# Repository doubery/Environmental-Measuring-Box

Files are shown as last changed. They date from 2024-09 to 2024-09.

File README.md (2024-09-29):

# Environmental-Measuring-Box
ESP32-based environmental measuring box for volume, temperature, humidity, air humidity, particulate matter, GPS

All measured data are sent to an influx database and in my case analyzed and displayed using grafana.

# Circuit diagram

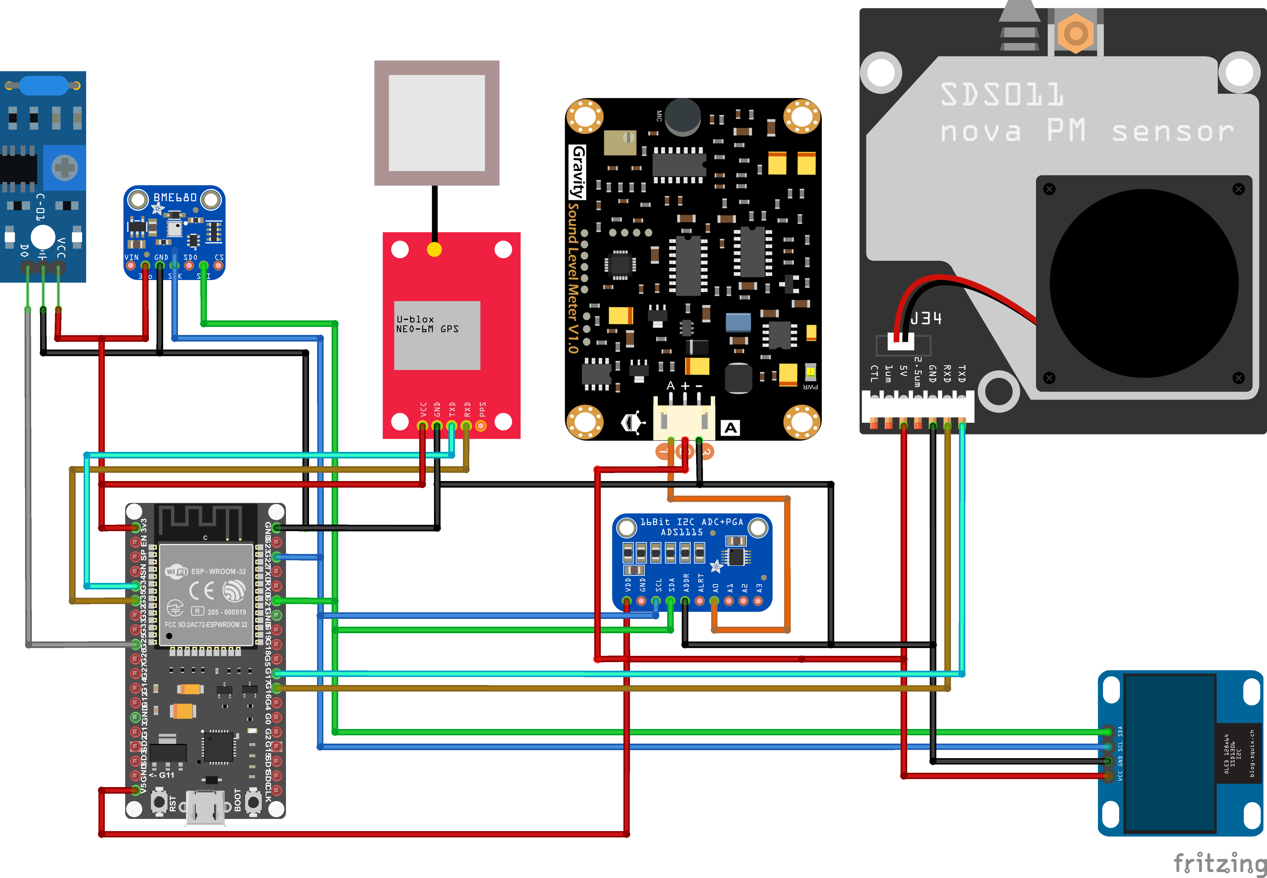
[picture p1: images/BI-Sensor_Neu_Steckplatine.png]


# Installation
Once all the parts have been printed, they can be assembled using m2 hexagon socket screws. <br/>
The ESP should be located on the adapter board and all sensors should be connected as follows (please refer to the wiring diagram). <br/>

#GPS#

TX = RX2 GPIO34       //GPS-RX2 <br/>
RX = TX2 GPIO35       //GPS-TX2 <br/>
GND <br/>
3.3V <br/>

#SDS#

RX = Serial2	  GPIO017   //SDS-RX1 <br/>
TX = Serial2   	GPIO016   //SDS-TX1 <br/>
GND <br/>
5V <br/>

#ADS1115# !I2C!

SDA = GPIO 21 <br/>
SCL = GPIO 22 <br/>
GND <br/>
5V <br/>

BME680 !I2C!

SDA = GPIO 21 <br/>
SCL = GPIO 22 <br/>
GND <br/>
3.3V <br/>

#DF-Robot-Micro#

Analog = ADS1115 A0 <br/>
GND <br/>
5V <br/>

#Shake Sensor#

PIN 25 <br/>
GND  <br/>
3,3V <br/>

Display !I2C!
SDA = GPIO 21 <br/>
SCL = GPIO 22 <br/>
GND <br/>
3,3V <br/>

The first Scetch (Webconfig.ino) can now be compiled and uploaded to the ESP, pay attention to the correct WLAN data on line 29 and 30. <br/>
If the ESP restart is completed, the IP (find out via your router) of the ESP can be called up. <br/>
It may also work to simply put the link in your browser http://Station.local <br/>

Now the basic data for communication with your InfluxDB can be stored:

- Name of the sensor
- Destination address of the InfluxDB
- InfluxDB token
- InfluxDB organization
- InfluxDB Bucket

Once the entered data has been accepted, the main firmware (Station-V1.x) can be uploaded.

After this, the sensor is restarting and is now connected to your WiFi.  <br/>
If you want to disconnect the sensor of your wifi, to connect to another WiFi, go to the webpage over the ip address, or http://station_< your defined number in the webconfig >.local  <br/>
Now the should restart and starts a hotspot. You can now follow the steps on the display. <br/>
(Or simply connect a Mobile device to the hotspot and follow the steps on the phone) <br/>

# Used Parts

- ESP32‑IO Development Expansion Board
- ESP32 NodeMCU (Check the correct PIN-Number)
- GPS GY-NEO6MV2
- DfRobot Sound Level Meter
- Analog-Digital-Converter ADS1115
- Temp/Humidity BME680
- Dust-Sensor SDS011 with little pipe of ~3cm (8mm) <br/>
  INFO: On the original cable, the well-known JST 2.54 connectors were attached to the side of the esp
- Cylinder head screws Hexagon socket DIN 912 2&4mm
- AZDelivery 0.96 Zoll OLED Display
- AZDelivery SW420 Vibration Sensor
- Jumper Cables

# Pictures

Fully assembled sensor <br/>


Webconfig <br/>
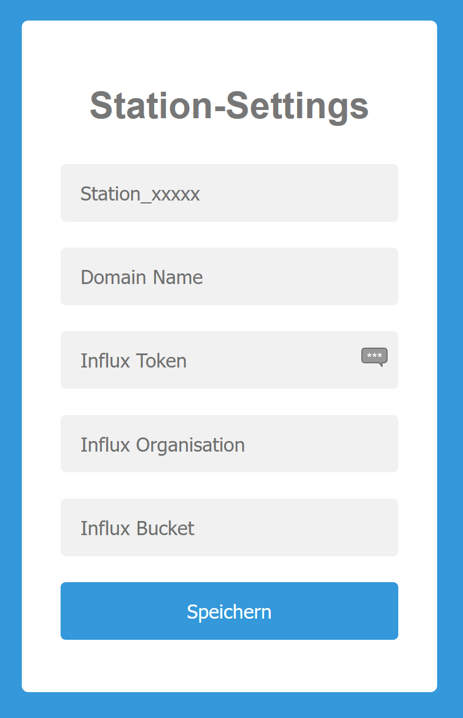
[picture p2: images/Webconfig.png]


Settings page after uploaded firmware "station-V1.7.bin" <br/>
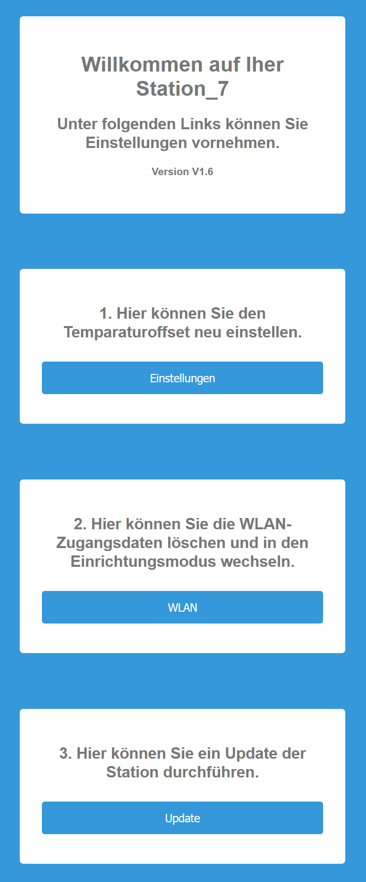
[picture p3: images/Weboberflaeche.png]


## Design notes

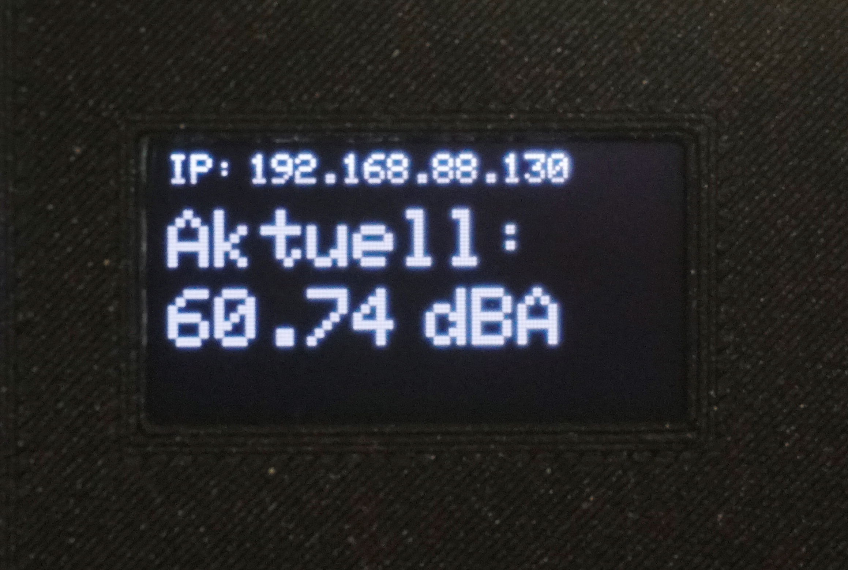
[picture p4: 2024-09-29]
images/Messung_aktuell_Ausschnitt.JPG

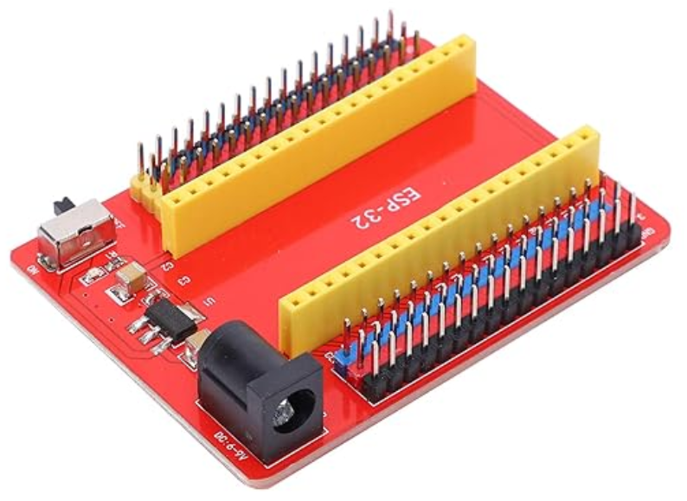
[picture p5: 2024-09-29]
images/Adapterplatine.png

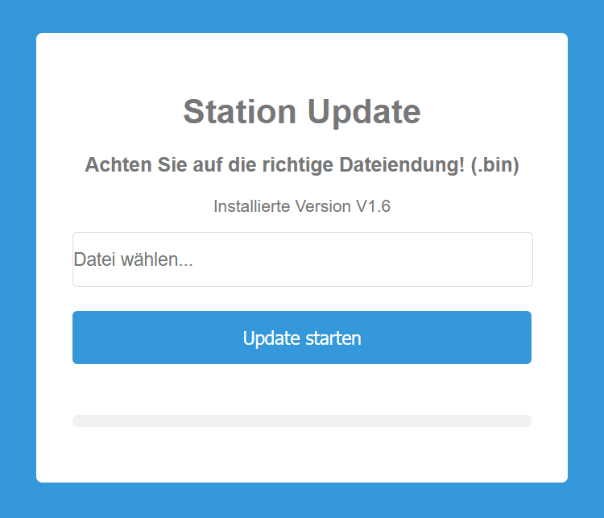
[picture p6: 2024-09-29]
images/Update.png

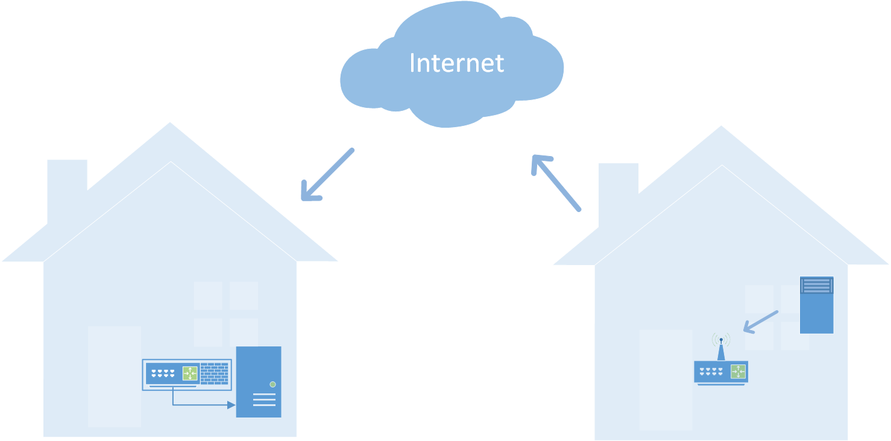
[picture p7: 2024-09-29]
images/Überblick.png

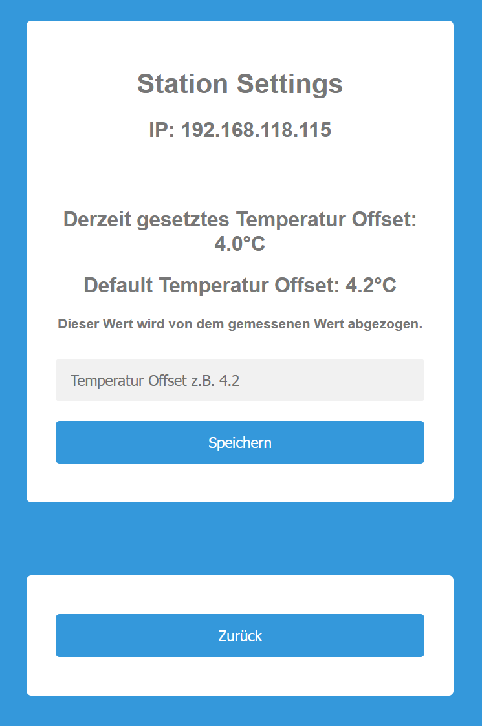
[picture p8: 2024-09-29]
images/Temp-Offset.png

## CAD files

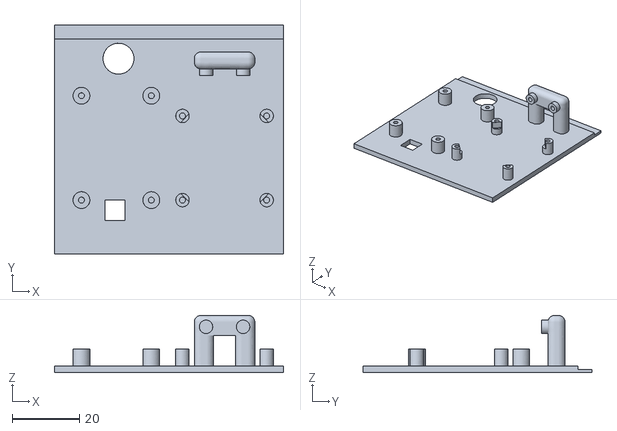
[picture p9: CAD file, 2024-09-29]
3d-print-parts/Zwischenboden-.stl
68.0 x 68.0 x 17.0

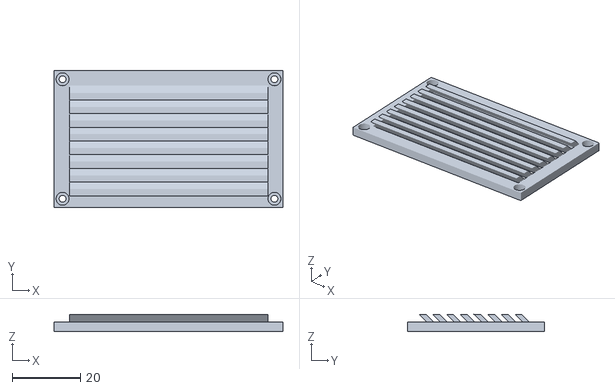
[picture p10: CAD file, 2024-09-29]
3d-print-parts/Lamellen.stl
66.9 x 39.9 x 5.00

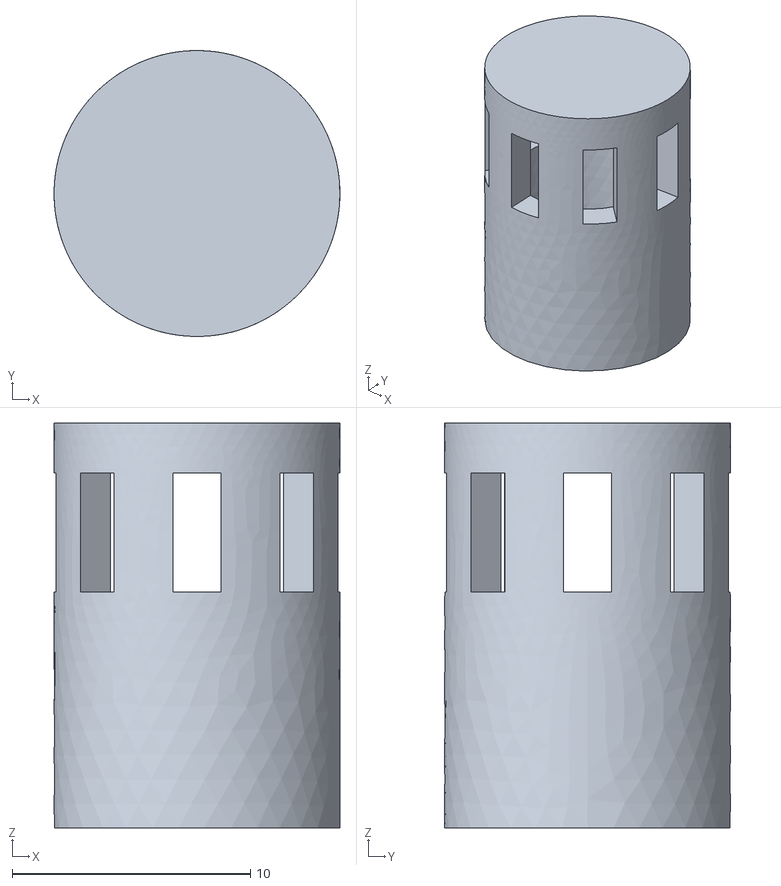
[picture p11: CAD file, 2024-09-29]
3d-print-parts/Staubkappe-SDS011.stl
12.0 x 12.0 x 17.0

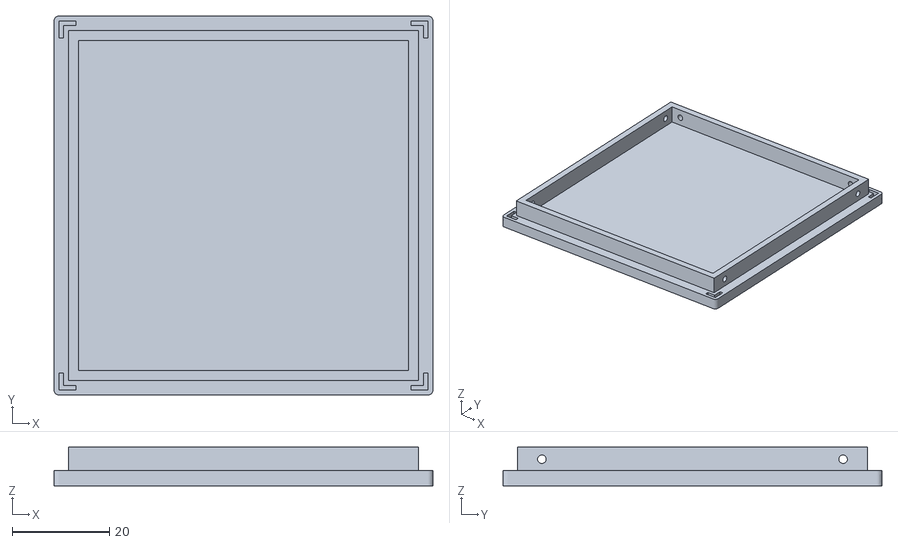
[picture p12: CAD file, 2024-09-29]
3d-print-parts/Deckel.stl
78.0 x 78.0 x 8.00

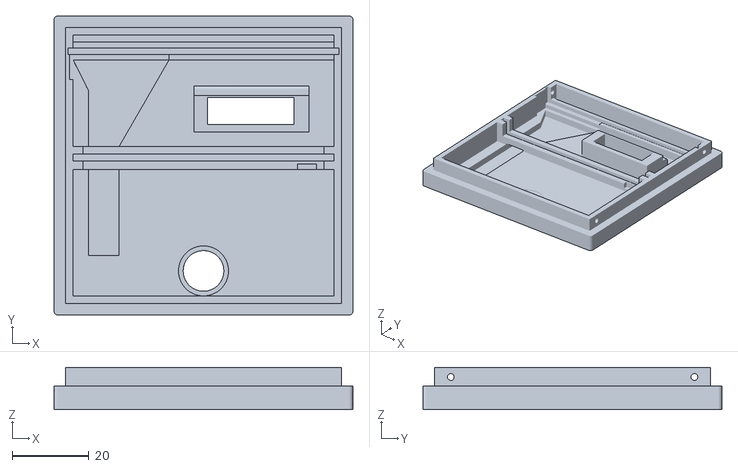
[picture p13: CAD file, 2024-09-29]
3d-print-parts/Boden-ohne-Display.stl
78.0 x 78.0 x 11.0

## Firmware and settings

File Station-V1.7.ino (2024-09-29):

//Umweltdaten und Laermmesssensor der BI-LZH mit OLED
#include <WiFiManager.h>
//#include <WiFiClient.h>
//#include <WiFiClientSecure.h>
#include <InfluxDbClient.h>
#include "Adafruit_BME680.h"
#include "SdsDustSensor.h"
#include <TinyGPS++.h>
#include <HardwareSerial.h>
#include <Wire.h>
#include <SPI.h>
#include <Adafruit_Sensor.h>
#include <Adafruit_ADS1X15.h>
#include <Update.h>
#include <WebServer.h>
#include <ESPmDNS.h>
#include <Preferences.h>
#include <Adafruit_GFX.h>
#include <Adafruit_SSD1306.h>

//OLED-Groesse festlegen
#define SCREEN_WIDTH 128 // OLED display width, in pixels
#define SCREEN_HEIGHT 64 // OLED display height, in pixels
#define OLED_RESET -1 

//Deklaration des SSD1306 display verbunden ueber I2C (SDA, SCL pins)
Adafruit_SSD1306 display(SCREEN_WIDTH, SCREEN_HEIGHT, &Wire, -1);

//==============================================================
//                     Festlegung der globalen Variablen
//==============================================================
String device, sname, snr, sversion, ssid, wpakey, tempoffset, sealevel, dname, idbtoken, idborg, idbbucket, settings, delwifiok, updates, info, ip;
int shakepinstate = 0; 
int display_available = 1;
int period = 30000;
unsigned long time_now = 0;

#define shakepin 25

char myIpString[24];

//Setzen der Zeitzone, falls SSL Verwendet wird ist dies notwendig
// Set timezone string according to https://www.gnu.org/software/libc/manual/html_node/TZ-Variable.html
//  Central Europe: "CET-1CEST,M3.5.0,M10.5.0/3"
#define TZ_INFO "CET-1CEST,M3.5.0,M10.5.0/3"

//==============================================================
//                     SSL-Zertifikat wird nicht benoetigt
//==============================================================
const char* root_ca = "";

//==============================================================
//                     Webserverconfig
//==============================================================
//Festlegung des Style fuer die Weboberflaeche
String style =
"<style>#file-input,input{width:100%;height:44px;border-radius:4px;margin:10px auto;font-size:15px}"
"input{background:#f1f1f1;border:0;padding:0 15px}body{background:#3498db;font-family:sans-serif;font-size:14px;color:#777}"
"#file-input{padding:0;border:1px solid #ddd;line-height:44px;text-align:left;display:block;cursor:pointer}"
"#bar,#prgbar{background-color:#f1f1f1;border-radius:10px}#bar{background-color:#3498db;width:0%;height:10px}"
"form{background:#fff;max-width:380px;margin:75px auto;padding:30px;border-radius:5px;text-align:center}"
".btn{background:#3498db;color:#fff;cursor:pointer}</style>";

//Fetlegung der delwifi Website
String wifi = 
"<meta http-equiv=content-type content=text/html; charset=utf-8>"
"<form action=delwifi>"
"<h1>Station WiFi-Settings</h1>"
"<h2>WLAN Zugangsdaten wirklich löschen?</h2>"
"<h2>Im Anschluss bitte den Anweisungen auf dem Display folgen.</h2>"
"<input type=submit onclick=check(this.form) class=btn value=Löschen></form>"
"<form action=info>"
"<input type=submit onclick=check(this.form) class=btn value=Zurück></form>"
"<script>"
"</script>" + style;

//Festlegung der saved Website
String saved = 
"<meta http-equiv=content-type content=text/html; charset=utf-8>"
"<form action=saved>"
"<h1>Station-Einstellungen wurden erfolgreich gesetzt!</h1>"
"<h2>Die Station startet nun neu, danach sind die Einstellungen übernommen.</h2></form>"
"<script>"
"</script>" + style;

//Webserver auf Port 80 legen
WebServer server(80);

//Flashspeicher initialisieren
Preferences preferences;

//Verschluesselung zur uebertragung der Daten, noch nicht aktiv fehlende SSL Unterstuetzung
//WiFiClientSecure client2;

//Influx client Instanz erstellen
InfluxDBClient client;

//Setzen der Software-Serial-Pins für GPS
#define RX2 32 //GPS-RX2 alt34
#define TX2 33 //GPS-TX2 alt35

//Anlegen der Instanzen fuer die Sensoren
Adafruit_ADS1115 ads;
Adafruit_BME680 bme;
SdsDustSensor sds(Serial2);
TinyGPSPlus gps;
HardwareSerial SerialGPS(1);

//Double Struct fuer die Daten des GPS-Empfaengers (Vorgabe der Library)
struct GpsDataState_t {
  double originLat = 0;
  double originLon = 0;
  double originAlt = 0;
  double distMax = 0;
  double dist = 0;
  double altMax = -999999;
  double altMin = 999999;
  double spdMax = 0;
  double prevDist = 0;
};
GpsDataState_t gpsState = {};

//Einstellen des ADS1115 auf den richtigen Messbereich
int adc;
float maxvolt = 6.144, volt, vdd, dbvalue = 0.0;

//Funktion zum loeschen der WLAN-Zugangsdaten
void delWifi(){
  preferences.remove("ssid");
  preferences.remove("wpakey");
  preferences.end();
  Serial.println("WLAN-Daten erfolgreich geloescht!");
  server.sendHeader("Connection", "close");
  //Rufe die Seite delwifiok auf
  server.send(200, "text/html", delwifiok);
  delay(10000);
  ESP.restart();
}

//Funktion zur speicherung der korrektur Einstellungen
void save(){
  tempoffset = server.arg("tempoffset");
  if (tempoffset != ""){//Temperatur Offset z.B. 4.2
    preferences.putString("tempoffset", tempoffset);
    Serial.println("Temperatur-Offset erfolgreich gespeichert!");
  }else{
    preferences.putString("tempoffset", "4.2");
    Serial.println("Temperatur-Offset erfolgreich gespeichert!");
  }
  preferences.end();
  server.sendHeader("Connection", "close");
  //Rufe die Seite /saved auf
  server.send(200, "text/html", saved);
  delay(10000);
  ESP.restart();
}

//Funktion zum Auslesen des Status des Shakepin Sensors
bool read_shakepin(){
  if (digitalRead(shakepin) == HIGH){
    return true;
  }else{
    return false;
  }
}

//==============================================================
//                           SETUP
//==============================================================
void setup() {
  Serial.begin(9600);
  delay(250);
  
  //Display starten
  if(!display.begin(SSD1306_SWITCHCAPVCC, 0x3C)) { // Address 0x3D for 128x64
    Serial.println("Kein Display erkannt, starte ohne Displaykonfiguration");
    //setze variable display_available auf 0 wenn kein display erkannt
    display_available = 0;
    for(;;);
  }
  //if abfrage wenn display_available == 0, dann ueberspringen, sonst initialisieren
  if(display_available == 1){
    display.clearDisplay();
    display.display();
    display.setTextSize(1);
    display.setTextColor(WHITE);
    display.setCursor(16, 20);
    display.setTextSize(2);
    display.println("-Starte-");
    display.display();
  }
  delay(500);
  
  //Serielle Schnittstelle fuer den GPS-Sensor einrichten
  SerialGPS.begin(9600, SERIAL_8N1, RX2, TX2);
  delay(250);
  
  //ADC starten
  ads.begin();
  delay(250);
  
  //SDS01 Starten
  sds.begin();
  delay(250);
    
  //Ausgabe der SDS01 Fiirmwareversion
  Serial.println("");
  Serial.println(sds.queryFirmwareVersion().toString()); 
  delay(50);
  //Serial.println(sds.setQueryReportingMode().toString());
  //Serial.println(sds.setActiveReportingMode().toString());
  //Serial.println(sds.setContinuousWorkingPeriod().toString());
  delay(50);
  //Temperatursensor starten
  bme.begin();
  delay(50);
  //EEPROM Einlesen
  preferences.begin("S-Settings", false);
  //ADS Gain eistellen
  ads.setGain(GAIN_ONE);
  //Festlegung des Shakepin Pins
  pinMode(shakepin, INPUT);
  
  //Auslesen der Einstellungen aus dem Flashspeicher
  sname = preferences.getString("sname", "");
  snr = preferences.getString("snr", "");
  dname = preferences.getString("dname", "");
  dname = dname + ":8086";
  idbtoken = preferences.getString("idbtoken", "");
  idborg = preferences.getString("idborg", "");
  idbbucket = preferences.getString("idbbucket", "");
  sversion = preferences.getString("sversion", "");
  ssid = preferences.getString("ssid", "");
  wpakey = preferences.getString("wpakey", "");
  tempoffset = preferences.getString("tempoffset", "");
  sealevel = preferences.getString("sealevel", "");
  //Wenn das tempoffset 0.00 oder leer ist, setze es auf 4.2 (Standardwert)
  if(tempoffset == "0.00" || tempoffset == ""){
    tempoffset = "4.2";
  }
  //Wenn das sealevel 0.00 oder leer ist, setze es auf 1013.25 (Standardwert)
  if(sealevel == "0.00" || sealevel == ""){
    sealevel = "1013.25";
  }
  //Ausgabe diverser Infos beim Start
  Serial.println("Daten aus dem Speicher:");
  Serial.println(sname.c_str());
  Serial.println(snr);
  Serial.println(sversion);
  Serial.println(dname.c_str());
  Serial.println(idbtoken.c_str());
  Serial.println(idborg.c_str());
  Serial.println(idbbucket.c_str());
  Serial.println(ssid);
  Serial.println(wpakey);
  Serial.println(tempoffset);
  Serial.println(sealevel);
  Serial.println("-----------------------------------");

  //Wenn keine Anmeldedaten fuer das WLAN vorhanden sind, setze AP-Mode und warte auf Benutzereingabe
  if (ssid == ""){
    Serial.println("Keine Anmeldedaten vorhanden!");
    WiFiManager wifiManager;
    WiFi.mode(WIFI_STA); //Aceespoint-Modus
    WiFi.config(INADDR_NONE, INADDR_NONE, INADDR_NONE, INADDR_NONE);
    WiFi.setHostname(sname.c_str());
    Serial.println("Accesspoint wird gestartet");
    //Starte WiFiManager im AP-Mode
    while(WiFi.status() != WL_CONNECTED) {
      if(display_available == 1){
        display.clearDisplay();
        display.display();
        display.setTextSize(1);
        display.setTextColor(WHITE);
        display.setCursor(0, 1);
        display.print("IP: 192.168.4.1");
        display.setCursor(0, 11);
        display.print("SSID:    ");
        display.setCursor(35, 11);
        display.println(sname.c_str());
        display.setCursor(0, 20);
        display.println("WLAN-Key: bi-lzh.de");
        display.setCursor(0, 40);
        display.println("Bitte verbinden Sie");
        display.setCursor(0, 50);
        display.println("sich mit diesem WLAN!");
        display.display();
      }
      wifiManager.startConfigPortal(sname.c_str(), "bi-lzh.de");
      //Serial.print("IP-Adresse: ");Serial.println(WiFi.localIP());

      //Nutze MDNS zur Namensaufloesung (Station_vwxyz)
      if (MDNS.begin(sname.c_str())) {
        MDNS.addService("http", "tcp", 80);
        Serial.println("MDNS gestartet!");    
      }
    }
    //Bei erfolgreicher Verbindung zum WLAN speichere die Benutzereingaben im Flash
    ssid = WiFi.SSID();
    wpakey = WiFi.psk();
    delay(50);
    preferences.putString("ssid", ssid.c_str());
    preferences.putString("wpakey", wpakey.c_str());
    Serial.println("WLAN-Daten in Speicher geschrieben");
    preferences.end();
    if(display_available == 1){
      display.clearDisplay();
      display.display();
    }
    delay(500);
    wifiManager.resetSettings();
    delay(50);
    ESP.restart();
  }
  //Wenn WLAN-Daten vorhanden sind versuche Aufbau der Verbindung
  else{
    int i = 0;
    //Lese die gespeicherten Verbindungsdaten aus dem Flash
    Serial.println("");
    Serial.println("Dies sind die gespeicherten Zugangsdaten zum Accesspoint: ");
    Serial.print("SSID: ");Serial.println(ssid);
    Serial.print("WPA-Key: ");Serial.println(wpakey);
    Serial.println("");
    //sname = sname.c_str();
    //bool setHostname(const char * sname);
    WiFi.config(INADDR_NONE, INADDR_NONE, INADDR_NONE, INADDR_NONE);
    WiFi.setHostname(sname.c_str());
    WiFi.begin(ssid.c_str(), wpakey.c_str());
    //WiFi.setHostname(sname.c_str());
    //Nutze MDNS zur Namensaufloesung (Station_vwxyz)
    if (MDNS.begin(sname.c_str())) {
      MDNS.addService("http", "tcp", 80);
      Serial.println("MDNS gestartet!");
     }
    delay(200);
    //Stelle die Verbindung mit den gespeicherten Zugangsdaten her
    Serial.print("Verbindung mit SSID: ");Serial.print(ssid);
    Serial.print(" und Password: ");Serial.print(wpakey);
    Serial.print(" wird aufgebaut ");
    //Warte bis Verbindung aufgebaut
    while(WiFi.status() != WL_CONNECTED) {
      Serial.print(".");
      i++;
      
      //NEU Test wenn WLAN nicht vorhanden und Shakepin == True, dann starte Captive-Portal -> alt delay(500);
      time_now = millis(); 

      while(millis() < time_now + 1000){
        if (read_shakepin()){
          shakepinstate = 1;
        }
      }
      if (shakepinstate == 1){
        Serial.println("WLAN nicht gefunden, shakepin = True");
        WiFiManager wifiManager;
        WiFi.mode(WIFI_STA); //Aceespoint-Modus
        WiFi.config(INADDR_NONE, INADDR_NONE, INADDR_NONE, INADDR_NONE);
        WiFi.setHostname(sname.c_str());
        Serial.println("Accesspoint wird gestartet");
        //Starte WiFiManager im AP-Mode
        while(WiFi.status() != WL_CONNECTED) {
          if(display_available == 1){
            display.clearDisplay();
            display.display();
            display.setTextSize(1);
            display.setTextColor(WHITE);
            display.setCursor(0, 1);
            display.print("IP: 192.168.4.1");
            display.setCursor(0, 11);
            display.print("SSID:    ");
            display.setCursor(35, 11);
            display.println(sname.c_str());
            display.setCursor(0, 20);
            display.println("WLAN-Key: bi-lzh.de");
            display.setCursor(0, 40);
            display.println("Bitte verbinden Sie");
            display.setCursor(0, 50);
            display.println("sich mit diesem WLAN!");
            display.display();
          }
          wifiManager.startConfigPortal(sname.c_str(), "bi-lzh.de");
          //Serial.print("IP-Adresse: ");Serial.println(WiFi.localIP());

          //Nutze MDNS zur Namensaufloesung (Station_vwxyz)
          if (MDNS.begin(sname.c_str())) {
            MDNS.addService("http", "tcp", 80);
            Serial.println("MDNS gestartet!");    
          }
        }
        //Bei erfolgreicher Verbindung zum WLAN speichere die Benutzereingaben im Flash
        ssid = WiFi.SSID();
        wpakey = WiFi.psk();
        delay(50);
        preferences.putString("ssid", ssid.c_str());
        preferences.putString("wpakey", wpakey.c_str());
        Serial.println("WLAN-Daten in Speicher geschrieben");
        preferences.end();
        if(display_available == 1){
          display.clearDisplay();
          display.display();
        }
        delay(500);
        wifiManager.resetSettings();
        delay(50);
        ESP.restart();
      }
      // ENDE NEU
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
void loop(void) {

  //Aufruf der Funktion waitforclient zum Aufruf der Weboberflaeche
  waitforclient();
  //Aufruf der Funktion read_sds fuer die Feinstaubmessung
  read_sds();
  //Aufruf der Funktion waitforclient zum Aufruf der Weboberflaeche
  waitforclient();  
  //Aufruf der Funktion read_bmeandgps fuer das auslesen des Temperatur und GPS-Sensors
  read_bmeandgps();
  //Aufruf der Funktion waitforclient zum Aufruf der Weboberflaeche
  waitforclient();
  
  //Beginn der Lautstaerkemessung fuer insg. 5Min
  Serial.println("Messe Lautstaerke");
  for (int count = 0; count < 10; count++) {
    //Aufruf der Funktion readdb fuer die Lautstaerkemessung
    readdb();
    Serial.print("Anzahl an durchlaeufen der dB Messung: ");Serial.println(count);
  }
}

//Funktion waitforclient welche den Webserver anweist auf eine Clientverbindung zu warten
void waitforclient(){
  time_now = millis();
  while(millis() < time_now + 250){
    server.handleClient();
  }
}

//Funktion readdb zum Auslesen des Lautstaerkesensors
void readdb(){
  Point sensor(sname.c_str()); 
  sensor.clearFields();
  sensor.addTag("Serialnumber", snr.c_str());
  //Festlegung der benoetigten Variablen
  float sum, adv, volts0;
  int16_t adc0;
  float  dbvaluemax = 0, dbvaluemin = 130, dbvalueavg = 0;
    //Pruefe ob Datenbankverbindung erfolgreich
    if (client.validateConnection()) {
      Serial.println("Verbindung zur Datenbank erfolgreich");
        for (int counti = 0; counti < 300; counti++) {// fuer 30 sekunden messen
          time_now = millis();
          //Pruefe ob ein Client eine Verbindung zum Webserver aufbauen will 
          while(millis() < time_now + 100){
              server.handleClient();
              //Pruefe ob der Shakepin 1 ist
              if (read_shakepin()){
                shakepinstate = 1;
              }
          }
          //Lese den Kanal 0 des ADS1115 aus
          adc0 = ads.readADC_SingleEnded(0);
          //Erzeuge Volt Messwerte
          volts0 = ads.computeVolts(adc0);
          //Berechne das dB Value
          dbvalue = volts0 * 50.0;
          //Zeige aktuellen Messwert in der Konsole
          Serial.println("-------------------------------");
          Serial.print("AIN0: "); Serial.print(adc0); Serial.print("  "); Serial.print(volts0); Serial.print("V"); Serial.print("  "); Serial.print(dbvalue); Serial.println("dBA");
          //Fuege der Variable dbvalueavg den aktuellen Messwert hinzu 
          dbvalueavg = dbvalueavg + dbvalue;
          //Alle 100ms wird verglichen, ob ein gemessener Wert groesser oder kleiner dem vorherigen ist somit wird bestimmt welches der lauteste oder leiseste Messwert ist
          if (dbvalue >= dbvaluemax)
          {
            dbvaluemax = dbvalue;
          }
          if (dbvalue < dbvaluemin)
          {
            dbvaluemin = dbvalue;
          }
          //Wenn Shakepin true und Display ist verfuegbar zeige folgendes an
          if (shakepinstate == 1 && display_available == 1){
            //Zeige aktuellen L-Messwert auf OLED
            display.clearDisplay();
            display.setTextSize(1);
            display.setTextColor(WHITE);
            display.setCursor(0, 1);
            display.println("IP:");
            display.setCursor(21, 1);
            display.println(ip);
            display.setTextSize(2);
            display.setCursor(0, 15);
            display.print("Aktuell:");
            display.setCursor(0, 35);
            display.println(dbvalue);
            display.setCursor(55, 35);
            display.print(" dBA");
            display.display(); 
          }
          Serial.print("L-Counter: "); Serial.println(counti);
        }
      if(display_available == 1){
        //Schalte Beleuchtung des OLED wieder aus
        display.clearDisplay();
        display.display();
      }
      //Setze den Shakepin fuer den naechsten Durchlauf auf 0
      shakepinstate = 0;
      //Zeige alle festgelegten Messwerte der Messreie noch mal in der seriellen Konsole
      Serial.print("Aktuelle Lautstaerke gemessen: ");
      Serial.print(dbvalue); Serial.println("dBA");
      dbvalueavg = (dbvalueavg/300);//durch 300 Messungen teilen
      Serial.print("dbvaluemax = ");Serial.println(dbvaluemax);
      Serial.print("dbvaluemin = ");Serial.println(dbvaluemin);
      Serial.print("dbvalueavg = ");Serial.println(dbvalueavg);
      Serial.print("dbvalue    = ");Serial.println(dbvalue);
      sensor.clearFields();
      sensor.addField("dBAmax", dbvaluemax);
      sensor.addField("dBAmin", dbvaluemin);
      sensor.addField("dBAavg", dbvalueavg);
      sensor.addField("dBA", dbvalue);
      client.writePoint(sensor);
      Serial.println("Lautstaerkemessungen erfolgreich in Datenbank geschrieben!");
    }
    //Wenn keine Verbindung zur Datenbank, dann starte WLAN neu und warte 10sek
    else {
      int count = 0;
      Serial.print("InfluxDB connection failed: ");
      Serial.println(client.getLastErrorMessage());
      while (client.getLastErrorMessage() == "connection refused"){
        WiFi.reconnect();
        //Wenn das Display verfuegbar ist, zeige an, dasss die Verbindung zur Datenbank fehlgeschlagen ist
        if(display_available == 1){
          display.clearDisplay();
          display.setTextSize(1);
          display.setTextColor(WHITE);
          display.setCursor(0, 1);
          display.println("Keine Verbindung");
          display.setCursor(0, 11);
          display.println("zur Datenbank!");
          display.setCursor(0, 21);
          display.println("Warte auf");
          display.setCursor(0, 31);
          display.println("Verbindung...");
          display.display();
        }
        time_now = millis();
        //Pruefe ob ein Client eine Verbindung zum Webserver aufbauen will
        while(millis() < time_now + 10000){ 
          server.handleClient();
        }
        //Falls das Display verfuegbar war, schalte es aus
        if(display_available == 1){
          display.clearDisplay();
          display.display();
        }
        //Zaehle die Verbindungsversuche
        count++;
        Serial.println(count);
        client.validateConnection();
        client.getLastErrorMessage();
        Serial.println(client.getLastErrorMessage());
        if(count == 60){
          count = 0;
          delay(500);
          //ESP.restart(); Derzeit auskommentiert, da die Box sonst haeufig neustartet!...?
        }
      }
    }
}
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

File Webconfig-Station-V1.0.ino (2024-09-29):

#include <WiFi.h>
#include <WiFiClient.h>
#include <Wire.h>
#include <WebServer.h>
#include <ESPmDNS.h>
#include <Update.h>
#include <Preferences.h>
#include <Adafruit_GFX.h>
#include <Adafruit_SSD1306.h>

//Flashspeicher initialisieren
Preferences preferences;

//Server on port 80
WebServer server(80); 

//==============================================================
//               Festlegung der globalen Variablen
//==============================================================
//OLED-Groesse festlegen
#define SCREEN_WIDTH 128 // OLED display width, in pixels
#define SCREEN_HEIGHT 64 // OLED display height, in pixels
#define OLED_RESET -1 

//Deklaration des SSD1306 display verbunden ueber I2C (SDA, SCL pins)
Adafruit_SSD1306 display(SCREEN_WIDTH, SCREEN_HEIGHT, &Wire, -1);

//SSID and Password von deinem WLAN ##### ANPASSEN #############
const char* sssid = "Test";
const char* spassword = "xkokd208zr74hf,x0fk00v934";
char myIpString[24];
//SSID and Password von deinem WLAN ##### ANPASSEN #############

//Festlegung der globalen Variablen
String sversion, updates, ip; 
String myhostname = "Station_NEU";

//==============================================================
//                     Webserverconfig
//==============================================================
//Festlegung des Style fuer die Weboberflaeche
String style =
"<style>#file-input,input{width:100%;height:44px;border-radius:4px;margin:10px auto;font-size:15px}"
"input{background:#f1f1f1;border:0;padding:0 15px}body{background:#3498db;font-family:sans-serif;font-size:14px;color:#777}"
"#file-input{padding:0;border:1px solid #ddd;line-height:44px;text-align:left;display:block;cursor:pointer}"
"#bar,#prgbar{background-color:#f1f1f1;border-radius:10px}#bar{background-color:#3498db;width:0%;height:10px}"
"form{background:#fff;max-width:258px;margin:75px auto;padding:30px;border-radius:5px;text-align:center}"
".btn{background:#3498db;color:#fff;cursor:pointer}</style>";

// Einstellungswebsite
String settings = 
"<form action=save>"
"<h1>Station-Settings</h1>"
"<input name=sname placeholder='Station_xxxxx'> "
"<input name=dname placeholder='Domain Name'> "
"<input name=idbtoken placeholder='Influx Token'>"
"<input name=idborg placeholder='Influx Organisation'> "
"<input name=idbbucket placeholder='Influx Bucket'>"
"<input type=submit onclick=check(this.form) class=btn value=Speichern></form>"
"<script>"
"{window.open('/update')}"
"</script>" + style;

//Festlegung der Update erfolgreich Website
String updateok = 
"<meta http-equiv=content-type content=text/html; charset=utf-8>"
"<form action=updateok>"
"<h1>Update wurde erfolgreich geschrieben!</h1>"
"<h2>Die Station startet nun neu und ist in ein paar Sekunden wieder erreichbar.</h2></form>"
"<script>"
"</script>" + style;

//===============================================================
// Diese Funktionen werden durchlaufen beim Klick auf Speichern
//===============================================================
void handleForm() {
 //Festlegung der Variablen
 String sname = server.arg("sname");
 String snr = sname;
 //Entfernung des Namen aus der Seriennummer
 snr.replace("Station_", ""); 
 String dname = server.arg("dname");
 String idbtoken = server.arg("idbtoken");
 String idborg = server.arg("idborg");
 String idbbucket = server.arg("idbbucket");
 //Serial.print(idbbucket);

 //Umwandung der z.B Eingabe 8 als Seriennummer in 1008 da in der alten influxdb die Seriennummern im 1.000er Bereich lagen.
 if (strstr(sname.c_str(), "_1000") != NULL)
  {
     sname.replace("1000", "");
  }
  else if (strstr(sname.c_str(), "_100") != NULL)
  {
    sname.replace("100", "");
  }
  else if (strstr(sname.c_str(), "_10") != NULL)
  {
    sname.replace("10", "");
  }
  else if (strstr(sname.c_str(), "_1") != NULL)
  {
    sname.replace("1", "");
  }

  //Infoausgabe in der Konsole
  Serial.println("-----------------------------------");
  Serial.print("Eingelesen Station Name: ");Serial.println(sname);
  Serial.print("Eingelesen Station Number: ");Serial.println(snr);
  Serial.print("Eingelesen Domain Name: ");Serial.println(dname);
  Serial.print("Eingelesen InfluxDB Token: ");Serial.println(idbtoken);
  Serial.print("Eingelesen InfluxDB Organisation: ");Serial.println(idborg);
  Serial.print("Eingelesen InfluxDB Bucket: ");Serial.println(idbbucket);
  Serial.print("Eingelesen Station Version: ");Serial.println(sversion);

  //Speicherung der Daten im EEPROM/Flashspeicher
  preferences.putString("sname", sname);
  preferences.putString("snr", snr);
  preferences.putString("dname", dname);
  preferences.putString("idbtoken", idbtoken);
  preferences.putString("idborg", idborg);
  preferences.putString("idbbucket", idbbucket);
  preferences.putString("tempoffset", "4.2");
  preferences.putString("sealevel", "1013.25");
  Serial.println("Station-Settings in Speicher geschrieben");
  Serial.println("-----------------------------------");
  
  preferences.end();
  //Beendigung der Client-Server Verbindung
  server.sendHeader("Connection", "close");
  server.send(200, "text/html", updates);
  delay(100);
  //Neustart des Mikrokontrollers
  ESP.restart();
}
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
